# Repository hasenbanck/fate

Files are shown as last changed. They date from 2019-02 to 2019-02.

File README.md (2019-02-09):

# Fate

Fate is a annutation adapter to connect an electrostatic amplifier with a ADC for audio measurments.

It steps down the voltage from maximal 1.6 kVpp down to 40 Vpp. It also contains some diodes for
overvoltage protection (use low capacitance diodes).

## Simulation

[CircuitJS](https://www.falstad.com/circuit/circuitjs.html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)

## License
CERN Open Hardware License 1.2

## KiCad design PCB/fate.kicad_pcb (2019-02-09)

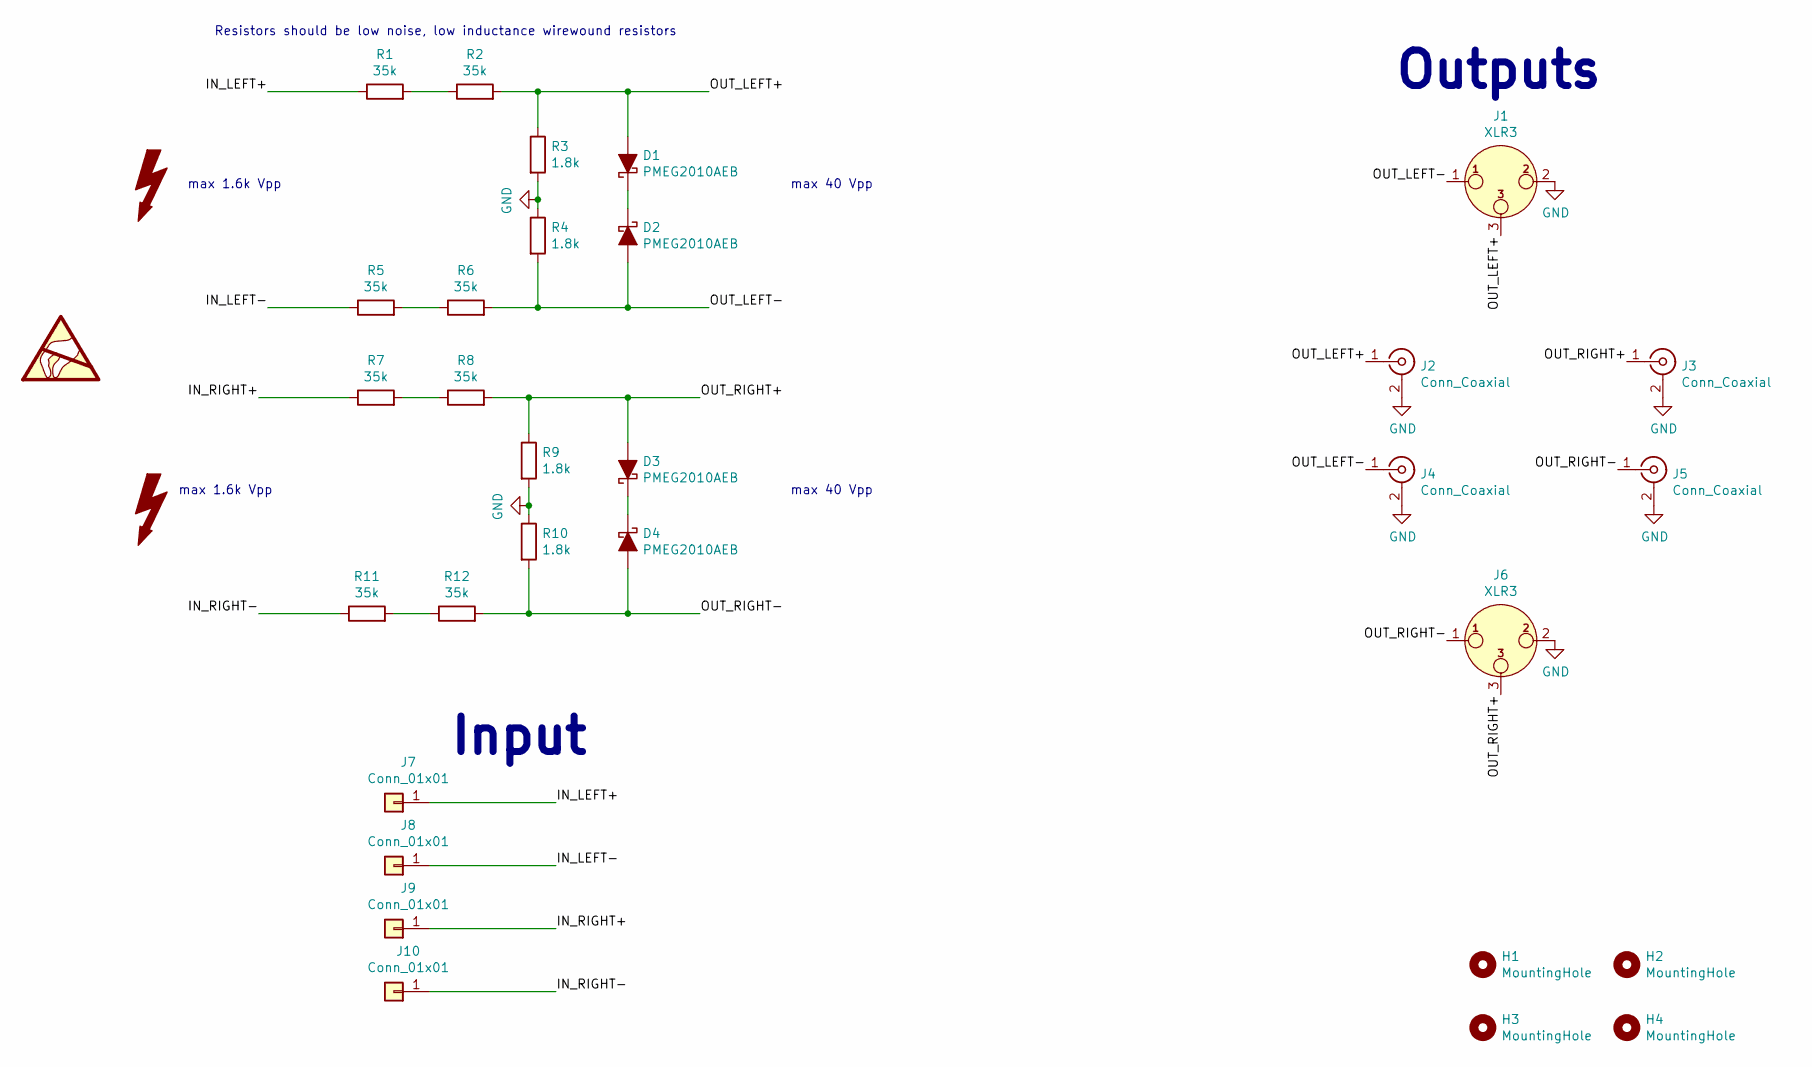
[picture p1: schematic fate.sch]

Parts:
D1, D2, D3, D4: PMEG2010AEB; D_SOD-523
H1, H2, H3, H4: MountingHole; MountingHole_3.2mm_M3_Pad
J1, J6: XLR3; XLR-NC3MA
J2, J3, J4, J5: Conn_Coaxial; CUI_RCJ-017
J7, J8, J9, J10: Conn_01x01; SolderWirePad_1x01_Drill2mm
R1, R2, R5, R6, R7, R8, R11, R12: 35k; R_Axial_Power_L25.0mm_W9.0mm_P30.48mm
R3, R4, R9, R10: 1.8k; R_Axial_DIN0516_L15.5mm_D5.0mm_P25.40mm_Horizontal
SYM1: SYM_ESD_Large; OSHW-Logo2_24.3x20mm_SilkScreen
SYM2, SYM3: SYM_Flash_Large; Symbol_HighVoltage_Type1_CopperTop_Big

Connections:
/IN_LEFT+: J7.1, R1.1
/IN_LEFT-: J8.1, R5.1
/IN_RIGHT+: J9.1, R7.1
/IN_RIGHT-: J10.1, R11.1
/OUT_LEFT+: D1.2 (A), J1.3, J2.1 (In), R2.2, R3.1
/OUT_LEFT-: D2.2 (A), J1.1, J4.1 (In), R4.2, R6.2
/OUT_RIGHT+: D3.2 (A), J3.1 (In), J6.3, R8.2, R9.1
/OUT_RIGHT-: D4.2 (A), J5.1 (In), J6.1, R10.2, R12.2
GND: J1.2, J2.2 (Ext), J3.2 (Ext), J4.2 (Ext), J5.2 (Ext), J6.2, R3.2, R4.1, R9.2, R10.1
unnamed: D1.1 (K), D2.1 (K)
unnamed: D3.1 (K), D4.1 (K)
unnamed: R1.2, R2.1
unnamed: R5.2, R6.1
unnamed: R7.2, R8.1
unnamed: R11.2, R12.1

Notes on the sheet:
Outputs
Input
max 1.6k Vpp
max 40 Vpp
Resistors should be low noise, low inductance wirewound resistors

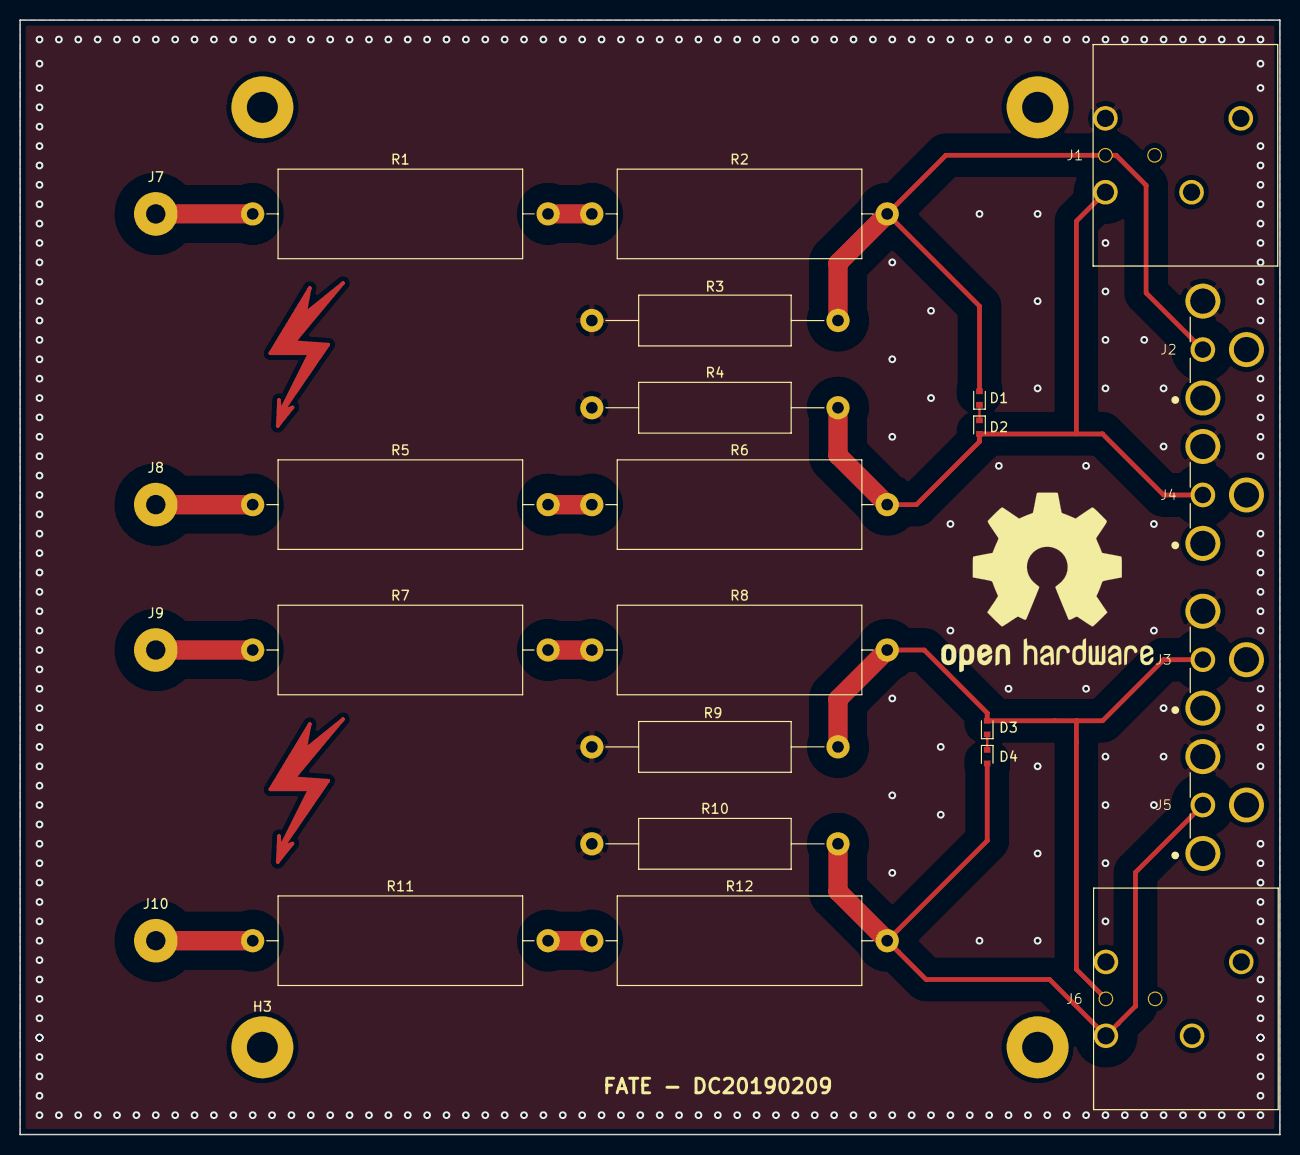
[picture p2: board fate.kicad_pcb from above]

Board: 2 copper layers, 130.0 x 115.0 mm, 33 parts (0 on the bottom side), 15 nets.

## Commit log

2019-02-08 Update resistors to use "NS" resistors
    "NS" resistors have a special winding to be "non-inductive".
    [fate.sch]
2019-02-09 Add ground reference between differential signal lines
    [fate.kicad_pcb, fate.sch]
